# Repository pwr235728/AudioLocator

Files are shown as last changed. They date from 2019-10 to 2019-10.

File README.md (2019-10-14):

# AudioLocator
Urządzenie umożliwiające wykrycie kierunku nadchodzącego dźwięku o znanych parametrach (sinusoidalny, o znanej częstotliwość).

Urządzenie składa się z:
* dwóch mikrofonów
* dwóch wzmacniaczy mikrofonowych 
* mikrokontroler STM32.

Mikrokontroler na podstawie dźwięku przechwyconego mikrofonami, oblicza kierunek z którego nadchodzi dźwięk.

Docelowo urządzenie ma zostać wyposarzone w dodatkowe mikrofony i umożłiwiać wykrywanie pozycji 3D źródła dźwięku.

## Model pytki PCB ze wzmacniaczami mikrofonowymi:
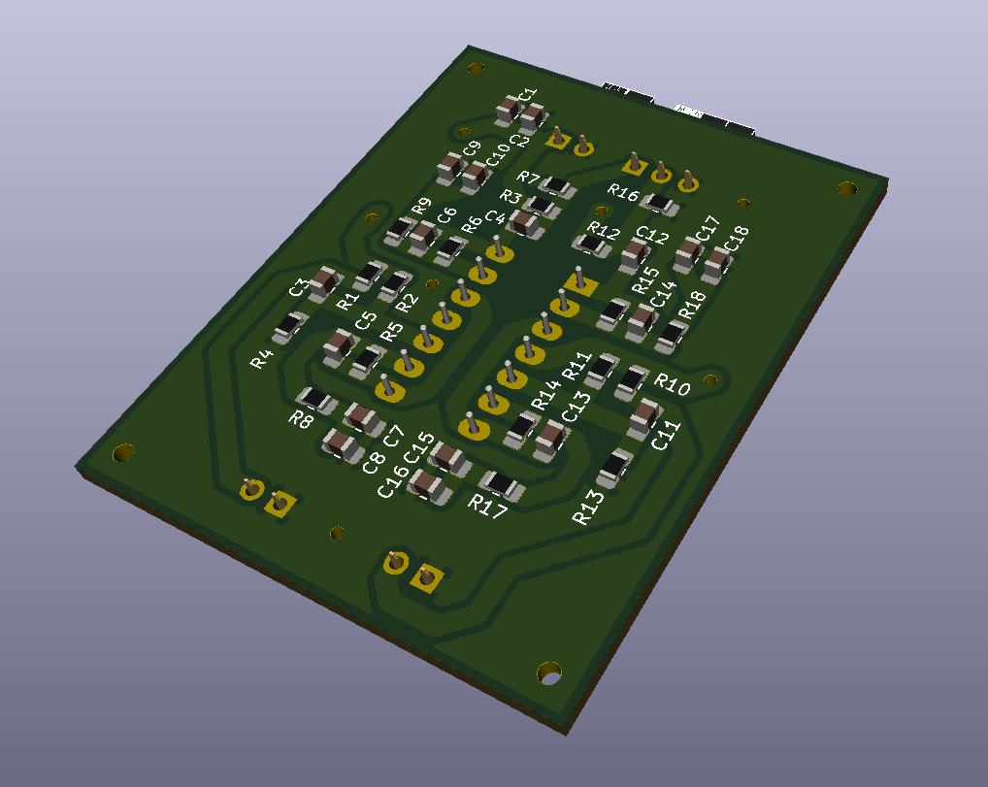
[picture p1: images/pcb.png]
PCB


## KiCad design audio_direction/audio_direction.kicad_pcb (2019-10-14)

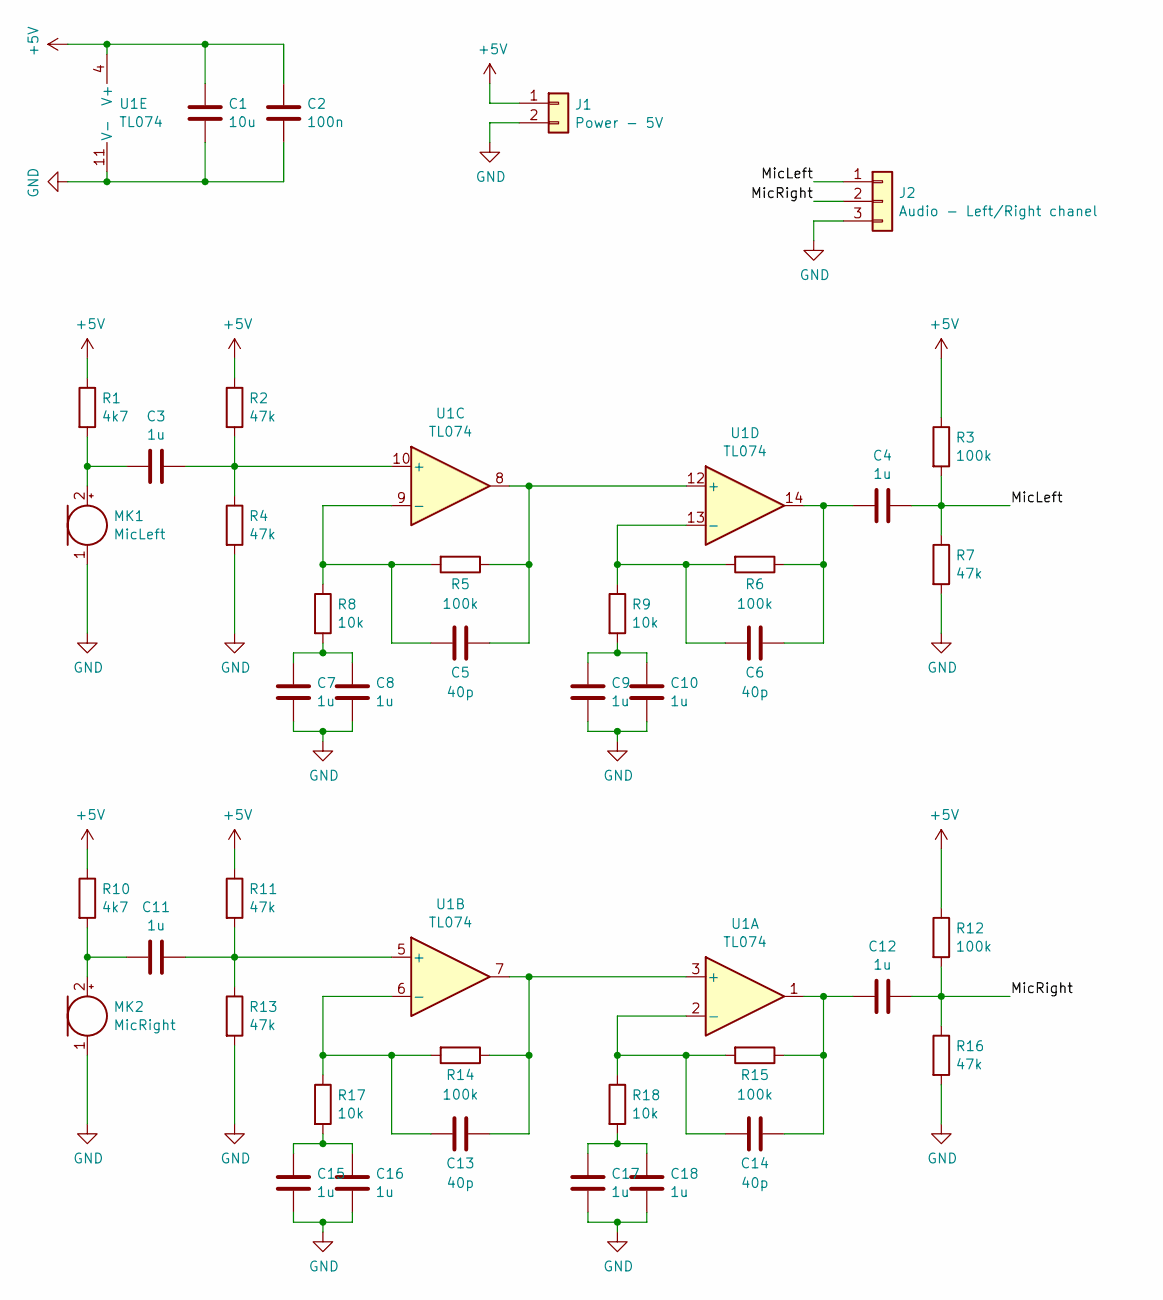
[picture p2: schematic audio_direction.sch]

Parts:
C1: 10u; C_0805_2012Metric_Pad1.15x1.40mm_HandSolder
C2: 100n; C_0805_2012Metric_Pad1.15x1.40mm_HandSolder
C3, C4, C7, C8, C9, C10, C11, C12, C15, C16, C17, C18: 1u; C_0805_2012Metric_Pad1.15x1.40mm_HandSolder
C5, C6, C13, C14: 40p; C_0805_2012Metric_Pad1.15x1.40mm_HandSolder
J1: Power - 5V; PinSocket_1x02_P2.54mm_Horizontal
J2: Audio - Left/Right chanel; PinSocket_1x03_P2.54mm_Horizontal
MK1: MicLeft; PinSocket_1x02_P2.54mm_Vertical
MK2: MicRight; PinSocket_1x02_P2.54mm_Vertical
R1, R10: 4k7; R_0805_2012Metric_Pad1.15x1.40mm_HandSolder
R2, R4, R7, R11, R13, R16: 47k; R_0805_2012Metric_Pad1.15x1.40mm_HandSolder
R3, R5, R6, R12, R14, R15: 100k; R_0805_2012Metric_Pad1.15x1.40mm_HandSolder
R8, R9, R17, R18: 10k; R_0805_2012Metric_Pad1.15x1.40mm_HandSolder
U1: TL074; DIP-14_W7.62mm_Socket_LongPads

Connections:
+5V: C1.2, C2.2, J1.1, R1.1, R2.1, R3.1, R10.1, R11.1, R12.1, U1.4 (V+)
/MicLeft: C4.1, J2.1, R3.2, R7.1
/MicRight: C12.1, J2.2, R12.2, R16.1
GND: C1.1, C2.1, C7.2, C8.2, C9.2, C10.2, C15.2, C16.2, C17.2, C18.2, J1.2, J2.3, MK1.1 (-), MK2.1 (-), R4.2, R7.2, R13.2, R16.2, U1.11 (V-)
unnamed: C3.1, R2.2, R4.1, U1.10 (+)
unnamed: C3.2, MK1.2 (+), R1.2
unnamed: C4.2, C6.1, R6.1, U1.14
unnamed: C5.1, R5.1, U1.8, U1.12 (+)
unnamed: C5.2, R5.2, R8.1, U1.9 (-)
unnamed: C6.2, R6.2, R9.1, U1.13 (-)
unnamed: C7.1, C8.1, R8.2
unnamed: C9.1, C10.1, R9.2
unnamed: C11.1, R11.2, R13.1, U1.5 (+)
unnamed: C11.2, MK2.2 (+), R10.2
unnamed: C12.2, C14.1, R15.1, U1.1
unnamed: C13.1, R14.1, U1.3 (+), U1.7
unnamed: C13.2, R14.2, R17.1, U1.6 (-)
unnamed: C14.2, R15.2, R18.1, U1.2 (-)
unnamed: C15.1, C16.1, R17.2
unnamed: C17.1, C18.1, R18.2

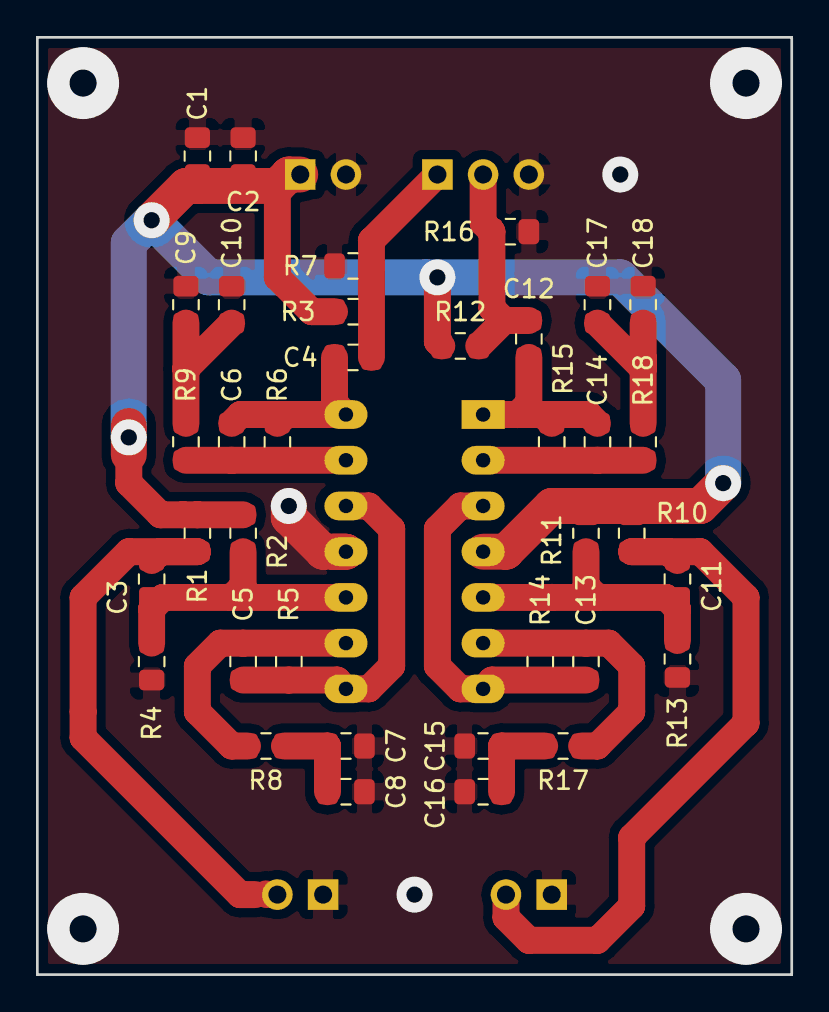
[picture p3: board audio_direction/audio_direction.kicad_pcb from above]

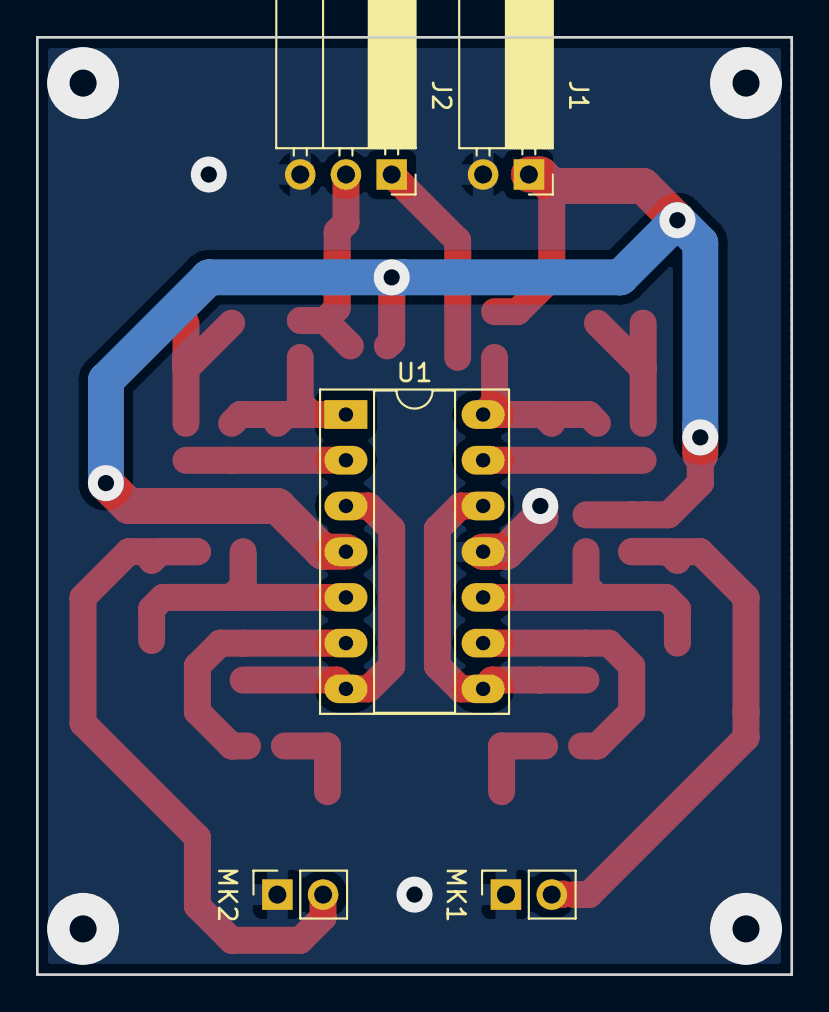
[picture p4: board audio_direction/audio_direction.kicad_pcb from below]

Board: 2 copper layers, 41.9 x 52.1 mm, 41 parts (5 on the bottom side), 20 nets.

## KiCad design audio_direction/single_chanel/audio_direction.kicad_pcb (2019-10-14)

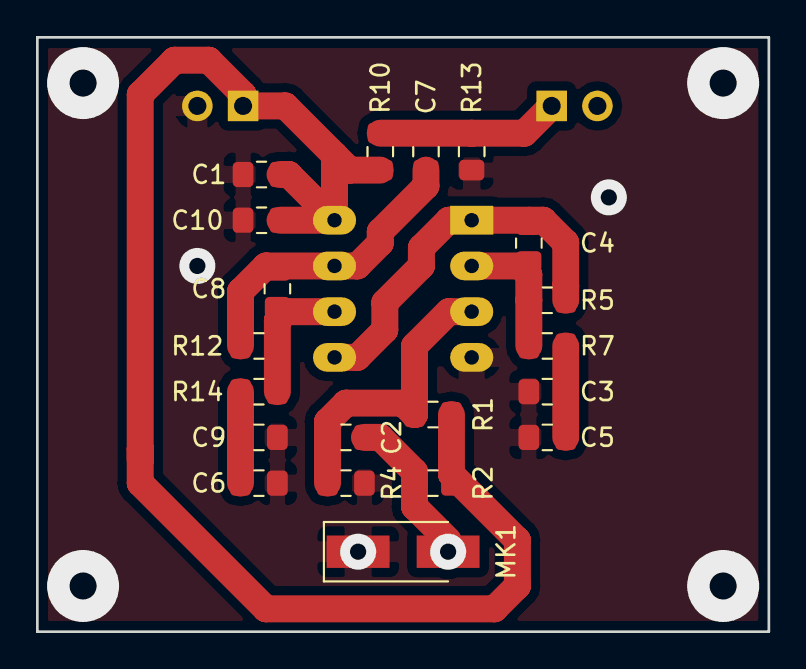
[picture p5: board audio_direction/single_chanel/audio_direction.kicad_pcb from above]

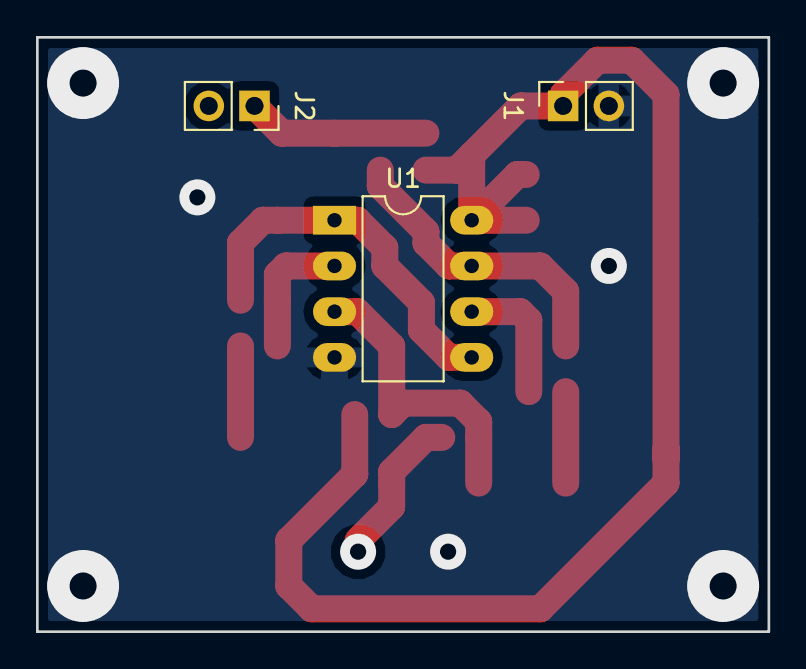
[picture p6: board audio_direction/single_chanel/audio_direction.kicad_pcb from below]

Board: 2 copper layers, 40.6 x 33.0 mm, 23 parts (3 on the bottom side), 11 nets.

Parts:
C1: 10u; C_0805_2012Metric_Pad1.15x1.40mm_HandSolder
C2, C3, C5, C6, C7, C9: 1u; C_0805_2012Metric_Pad1.15x1.40mm_HandSolder
C4, C8: 40p; C_0805_2012Metric_Pad1.15x1.40mm_HandSolder
C10: 100n; C_0805_2012Metric_Pad1.15x1.40mm_HandSolder
J1: Power - 5V; PinSocket_1x02_P2.54mm_Vertical
J2: Audio - Left/Right chanel; PinSocket_1x02_P2.54mm_Vertical
MK1: MicLeft; D_SMA_Handsoldering
R1, R4, R13: 47k; R_0805_2012Metric_Pad1.15x1.40mm_HandSolder
R2: 4k7; R_0805_2012Metric_Pad1.15x1.40mm_HandSolder
R5, R12: 90k; R_0805_2012Metric_Pad1.15x1.40mm_HandSolder
R7, R14: 10k; R_0805_2012Metric_Pad1.15x1.40mm_HandSolder
R10: 100k; R_0805_2012Metric_Pad1.15x1.40mm_HandSolder
U1: TL072; DIP-8_W7.62mm_LongPads

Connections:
+5V: C1.2, C10.2, J1.1, R1.1, R2.1, R10.1, U1.8
/MicLeft: C7.1, J2.1, R10.2, R13.1
GND: C1.1, C3.2, C5.2, C6.2, C9.2, C10.1, J1.2, MK1.1, R4.2, R13.2, U1.4
unnamed: C2.1, R1.2, R4.1, U1.3
unnamed: C2.2, MK1.2, R2.2
unnamed: C3.1, C5.1, R7.2
unnamed: C4.1, R5.1, U1.1, U1.5
unnamed: C4.2, R5.2, R7.1, U1.2
unnamed: C6.1, C9.1, R14.2
unnamed: C7.2, C8.1, R12.1, U1.7
unnamed: C8.2, R12.2, R14.1, U1.6

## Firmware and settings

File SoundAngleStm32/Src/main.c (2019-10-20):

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

/* Includes ------------------------------------------------------------------*/
#include "main.h"

/* USER CODE BEGIN Includes */
#include "audio_locator.h"
#include "signal_generator.h"
#include "audio_acquisition.h"

/* USER CODE END Includes */


UART_HandleTypeDef huart2;

/* USER CODE BEGIN PV */
extern uint32_t counter;
/* USER CODE END PV */

void SystemClock_Config(void);
static void MX_GPIO_Init(void);
static void MX_DMA_Init(void);
static void MX_ADC1_Init(void);
static void MX_TIM2_Init(void);
static void MX_USART2_UART_Init(void);
/**
  * @brief  The application entry point.
  * @retval int
  */
int main(void)
{
  

  /* MCU Configuration--------------------------------------------------------*/

  /* Reset of all peripherals, Initializes the Flash interface and the Systick. */
  HAL_Init();

  /* Configure the system clock */
  SystemClock_Config();

  /* Initialize all configured peripherals */
  MX_GPIO_Init();
  MX_DMA_Init();
  MX_ADC1_Init();
  MX_TIM2_Init();
  MX_USART2_UART_Init();
  /* USER CODE BEGIN 2 */
  AA_init();
  ComplexBuffer ref_signal;
  ref_signal =  ComplexBuffer_generate();

  /* USER CODE END 2 */

  /* Infinite loop */
  /* USER CODE BEGIN WHILE */

  while (1)
  {
	  if(AA_get_state() == DATA_STATUS_NEW)
	  {
		  AudioBuffer* audio_buff = AA_get_buffer();
		  float mag = AL_get_magnitude(&ref_signal, audio_buff);
		  Complex cmpl = AL_goertzel(audio_buff->ch_left_samples);
		  float mag2 = cmpl_get_mag(cmpl);
		  cmpl = AL_goertzel(audio_buff->ch_right_samples);
		  mag2 += cmpl_get_mag(cmpl);


		  float direction = AL_get_angle(&ref_signal, audio_buff);

		  uint8_t tx_buff[16];
		  uint32_t tx_len;
		  if(mag < 50) direction = 0;
		  tx_len = sprintf(tx_buff, "$%f %f;", mag, mag2);
		  HAL_UART_Transmit(&huart2, tx_buff, tx_len, 100);
		  /*for(int i=0;i<SAMPLE_BUFFER_LEN; i++)
		  {
			  uint8_t tx_buff[16];
			  uint32_t tx_len;
			  tx_len = sprintf(tx_buff, "$%f %f;", audio_buff->ch_left_samples[i], audio_buff->ch_right_samples[i]);
			  HAL_UART_Transmit(&huart2, tx_buff, tx_len, 100);
		  }*/
		  AA_release_buffer();
	  }
    /* USER CODE END WHILE */

    /* USER CODE BEGIN 3 */
  }
  /* USER CODE END 3 */
}

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


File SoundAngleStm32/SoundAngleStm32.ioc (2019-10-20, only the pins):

Mcu.UserName=STM32F446RETx
PA0-WKUP.Signal=ADCx_IN0
PA1.Signal=ADCx_IN1
PA13.GPIO_Label=TMS
PA13.Signal=SYS_JTMS-SWDIO
PA14.GPIO_Label=TCK
PA14.Signal=SYS_JTCK-SWCLK
PA2.GPIO_Label=USART_TX
PA2.Signal=USART2_TX
PA3.GPIO_Label=USART_RX
PA3.Signal=USART2_RX
PA5.GPIO_Label=LD2 [Green Led]
PA5.Signal=GPIO_Output
PB3.GPIO_Label=SWO
PB3.Signal=SYS_JTDO-SWO
PC13.GPIO_Label=B1 [Blue PushButton]
PC13.Signal=GPXTI13
PC14-OSC32_IN.Signal=RCC_OSC32_IN
PC15-OSC32_OUT.Signal=RCC_OSC32_OUT
PH0-OSC_IN.Signal=RCC_OSC_IN
PH1-OSC_OUT.Signal=RCC_OSC_OUT

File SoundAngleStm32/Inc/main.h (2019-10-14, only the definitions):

#define B1_Pin LL_GPIO_PIN_13
#define B1_GPIO_Port GPIOC
#define USART_TX_Pin LL_GPIO_PIN_2
#define USART_TX_GPIO_Port GPIOA
#define USART_RX_Pin LL_GPIO_PIN_3
#define USART_RX_GPIO_Port GPIOA
#define LD2_Pin LL_GPIO_PIN_5
#define LD2_GPIO_Port GPIOA
#define TMS_Pin LL_GPIO_PIN_13
#define TMS_GPIO_Port GPIOA
#define TCK_Pin LL_GPIO_PIN_14
#define TCK_GPIO_Port GPIOA
#define SWO_Pin LL_GPIO_PIN_3
#define SWO_GPIO_Port GPIOB

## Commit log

2019-10-14 image of pcb
2019-10-20 Implementacja Goertzel Filter do wykrycia częstotliwości i fazy sygnału
    [SoundAngleStm32 Debug.cfg]

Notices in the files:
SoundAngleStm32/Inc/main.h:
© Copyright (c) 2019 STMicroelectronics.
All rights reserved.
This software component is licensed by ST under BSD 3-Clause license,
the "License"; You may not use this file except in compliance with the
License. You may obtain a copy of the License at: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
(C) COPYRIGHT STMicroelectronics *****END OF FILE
